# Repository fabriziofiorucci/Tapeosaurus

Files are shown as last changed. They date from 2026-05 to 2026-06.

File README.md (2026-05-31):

# Tapeosaurus

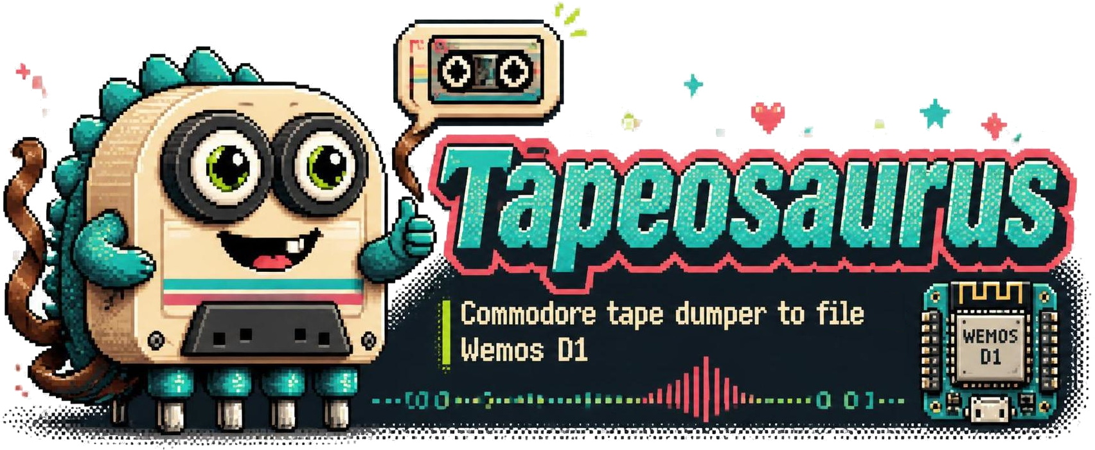
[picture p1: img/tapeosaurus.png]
Tapeosaurus


Cycle-accurate tape dumper for the **Commodore 16 / Plus/4**, **Commodore 64 / 128**, **ZX Spectrum**, and **MSX** running on a single Wemos D1 Mini (ESP8266) with a 3D-printable enclosure.

Inspired by Francesco Vannini's [TrueTape64](https://github.com/francescovannini/truetape64).

Supports C16/Plus4 standard tape and Novaload turbo, Commodore 64/128 tapes, ZX Spectrum standard ROM tapes, and MSX standard tapes — producing standard `.tap` v2 / `.tzx` / `.cas` files compatible with VICE, Fuse, Tapuino, TZXDuino, openMSX, and any other TAP/TZX/CAS-capable emulator or hardware.

---

## Supported tapes

* Commodore 16 & Plus4
* Commodore 64 & 128
* Spectrum
* MSX

---

## Hardware

### What you need

| Qty | Part | Note |
| --- | --- | --- |
| 1 | Wemos D1 Mini | Any revision; clones work fine |
| 1 | MP1584EN step-down module | Adjustable buck converter — set output to 5.00 V |
| 1 | MP1584EN step-down module | Adjustable buck converter — set output to 6.10 V |
| 1 | 10 kΩ resistor | READ voltage divider - in series with READ pin |
| 1 | 20 kΩ resistor | READ voltage divider - shunt to GND |
| 1 | 10 kΩ resistor | SENSE pull-up to 3.3 V |
| 1 | Green LED | "Tape play" indicator |
| 1 | Red LED | "Overflow" indicator |
| 1 | Yellow LED | "Power on" indicator |
| 2 | 390 Ω resistors | Green and red LED current limiters |
| 1 | 680 Ω resistor | Yellow LED current limiters |
| 1 | Passive piezo speaker | Tape audio feedback |
| 1 | 7-pin mini-DIN connector or salvaged cable | Commodore 16 Datasette connector |
| 1 | Mini tactile switch | Reset button |
| 1 | DC jack barrel connector with PCB mount | Power supply connector |
| 1 | >= 9V DC power supply | Powers both MP1584EN modules |

### MSX hardware notes

#### Using a Commodore tape player

MSX tapes can be dumped using a Commodore datasette, no firmware changes required.

#### Connecting an MSX tape player

MSX computers read tape via the **EAR** pin on the cassette connector (a 3.5 mm DIN jack or 8-pin DIN depending on the model). The EAR pin carries the audio signal from the tape deck at roughly 1 Vpp.

Use the same 10 kΩ / 20 kΩ voltage divider on the READ line as for Commodore tapes. No firmware changes are required — the `tapeosaurus.ino` sketch is identical; the CLI selects CHANGE edge mode automatically when `-model msx` is used.

#### MSX tape format

MSX uses a **Kansas City Standard (KCS)** variant FSK encoding:

| Baud rate | Bit 0 | Bit 1 |
|---|---|---|
| 1200 baud | 1 cycle @ 1200 Hz | 2 cycles @ 2400 Hz |
| 2400 baud | 1 cycle @ 2400 Hz | 2 cycles @ 4800 Hz |

Each byte is framed as: 1 start bit (0), 8 data bits (LSB first), 2 stop bits (1).

Output is a standard **.cas** file containing the 8-byte CAS sync header (`1F A6 DE BA CC 13 7D 74`) followed by decoded data, compatible with openMSX, fMSX, BlueMSX, CASDuino, and TZXDuino/CASduino.

### ZX Spectrum hardware notes

#### Using a Commodore tape player

Spectrum tapes can be dumped using a Commodore datasette, no firmware changes required.

#### Using a standard tape player

The Spectrum EAR socket outputs a 5 V audio signal (not TTL).  The same
**10 kΩ / 20 kΩ voltage divider** used for the Commodore READ line is suitable
here — connect the EAR tip to the divider input and the sleeve to GND.

The Spectrum has no motor-control line equivalent to SENSE; the capture starts
as soon as the CLI detects the first pulse.  Because `CAPTURE_WITHOUT_SENSE`
defaults to `0`, the firmware waits for the SENSE pin to go LOW before it
starts storing pulses.  For Spectrum use, either:

- wire a simple switch to the SENSE pin (pull it LOW when you press PLAY), **or**
- recompile the firmware with `#define CAPTURE_WITHOUT_SENSE 1` (the CLI will
  still wait for the first `CMD_PLAY_PRESSED` event, which in this mode fires
  on the first pulse rather than on the SENSE signal).

### Pin mapping

| Wemos Pin | GPIO | Function |
| --- | --- | --- |
| D1 | GPIO5  | Overflow LED (lit if data overflow triggered) |
| D4 | GPIO2  | Onboard LED (active LOW - lit while recording) |
| D5 | GPIO14 | SENSE from Datasette (INPUT\_PULLUP, switch to GND) |
| D6 | GPIO12 | READ from Datasette (via 10 kΩ/20 kΩ divider → 3.3 V) |
| D7 | GPIO13 | Passive piezo speaker |

### Schematics

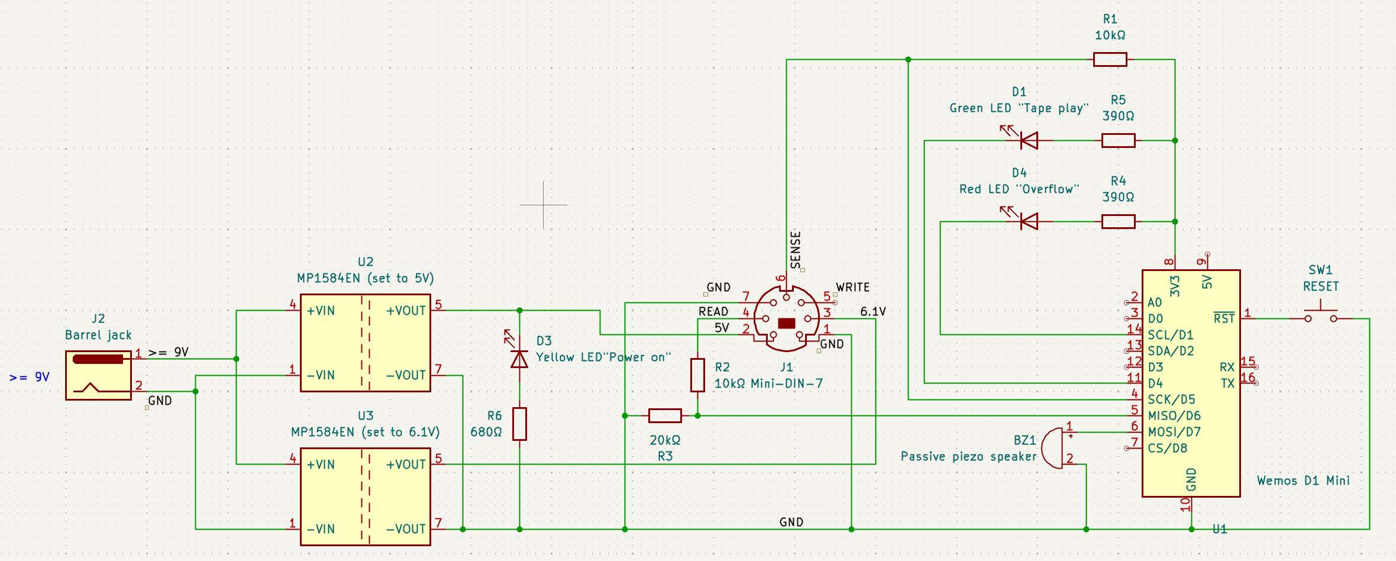
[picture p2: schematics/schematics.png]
Schematics


> ⚠ The ESP8266 is a 3.3 V device. The Datasette/EAR READ line is 5 V. The 10 kΩ / 20 kΩ divider is **mandatory** — skipping it will damage GPIO12.

### 3D-printable enclosure

Autodesk Fusion 360 files are provided [here](CAD).

### MP1584EN Step-Down Calibration

Each module must be pre-adjusted before connecting the Datasette.

**Module U2 — 5 V (Datasette logic supply)** Connect 12 V, measure OUT+ and adjust the trimpot to 5.00 V.

**Module U3 — 6.1 V (Datasette motor)** Connect 12 V, measure OUT+ and adjust the trimpot to 6.10–6.15 V. Recheck with the motor spinning under load. Values above 6.5 V risk burning the motor winding.

### Quick Sanity Checks Before First Use

- [ ] MP1584EN-U2 output reads 5.00 V (Datasette logic supply)
- [ ] MP1584EN-U3 output reads 6.10–6.15 V on MOTOR line (Datasette disconnected)
- [ ] Multimeter reads ~3.3 V on Wemos 3V3 pin
- [ ] SENSE pin reads ~3.3 V at idle (no tape playing)
- [ ] SENSE pin reads ~0 V when PLAY is pressed (with cassette inserted)
- [ ] No short between 5V and GND (continuity check — no beep)
- [ ] READ pin reads ~3.3 V with tape playing (signal swings around this level)

---

## Firmware

### Requirements

- Arduino IDE 1.8+ or 2.x
- ESP8266 Arduino core — add this URL in **File → Preferences → Additional Boards Manager URLs**:
`https://arduino.esp8266.com/stable/package_esp8266com_index.json`

### Board settings

| Setting | Value |
| --- | --- |
| Board | LOLIN(WEMOS) D1 R2 & mini |
| CPU Frequency | **80 MHz** ← must be 80, not 160 |
| Upload Speed  | 921600 |

> The `CLOCK_SCALE 40` constant (80 MHz ÷ 40 = 2 MHz ticks) is hardcoded. Changing CPU frequency without updating this value will corrupt all timing.

### Tuning options

| Define | Default | Description |
| --- | --- | --- |
| `CAPTURE_WITHOUT_SENSE` | `0` | Set to `1` to capture without waiting for PLAY — useful for Spectrum or READ wiring tests |

> Edge mode (FALLING/CHANGE) is not a compile-time setting. It is controlled entirely at runtime by the Python CLI over the serial control protocol. The default on power-up is FALLING (standard KERNAL) — safe until the CLI sets it otherwise.  For `-model spectrum` the CLI automatically sends `HOST_CMD_CHANGE` before capture.

---

## Python CLI

### Install

```
pip install -r cli/requirements.txt
```

### Usage

```
# Standard C16/Plus4 tape (PAL)
python3 cli/tapeosaurus.py -p /dev/ttyUSB0 -model c16 output.tap

# C16/Plus4 Novaload turbo
python3 cli/tapeosaurus.py -p /dev/ttyUSB0 -model c16 --novaload output.tap

# C16/Plus4 NTSC machine
python3 cli/tapeosaurus.py -p /dev/ttyUSB0 -model c16 --ntsc output.tap

# C16/Plus4 Extract PRG files after capture
python3 cli/tapeosaurus.py -p /dev/ttyUSB0 -model c16 --prg output.tap

# C64/128 tape (PAL)
python3 cli/tapeosaurus.py -p /dev/ttyUSB0 -model c64 output.tap

# ZX Spectrum tape → TZX (default, recommended)
python3 cli/tapeosaurus.py -p /dev/ttyUSB0 -model spectrum output.tzx

# ZX Spectrum tape → raw .tap
python3 cli/tapeosaurus.py -p /dev/ttyUSB0 -model spectrum --tap output.tap

# ZX Spectrum tape → TZX + extract .bin files
python3 cli/tapeosaurus.py -p /dev/ttyUSB0 -model spectrum --prg output.tzx

# MSX tape (1200 baud, default)
python3 cli/tapeosaurus.py -p /dev/ttyUSB0 -model msx output.cas

# MSX tape (2400 baud high-speed)
python3 cli/tapeosaurus.py -p /dev/ttyUSB0 -model msx --baud 2400 output.cas

# MSX tape → CAS + extract files
python3 cli/tapeosaurus.py -p /dev/ttyUSB0 -model msx --prg output.cas
```

Passing `--novaload` is required for C16/Plus4 Novaload turbo tapes. The CLI automatically sends the correct edge mode command to the ESP before waiting for PLAY, then selects the appropriate decode path after capture. No switches, no recompile.

### What happens at startup

1. CLI connects and waits 2 seconds for the ESP to boot
2. Sends `CMD_SET_EDGE_FALLING` or `CMD_SET_EDGE_CHANGE` depending on model / flags
3. Waits up to 3 seconds for the ESP's confirmation echo
4. Prints the confirmed edge mode and waits for PLAY

```
C16/Plus4 PAL — scale: 0.443362
Capturing → output.tap
→  Setting edge mode: FALLING (standard)
✔  Edge mode confirmed by device: FALLING (standard)
Waiting for PLAY (LED lights up)...
```

```
C64 PAL — scale: 0.492624
Capturing → output.tap
→  Setting edge mode: FALLING (standard)
✔  Edge mode confirmed by device: FALLING (standard)
Waiting for PLAY (LED lights up)...
```

```
ZX Spectrum — 3.5 MHz — output: .tzx
Capturing → output.tzx
→  Setting edge mode: CHANGE (Novaload/turbo)
✔  Edge mode confirmed by device: CHANGE (Novaload/turbo)
Waiting for PLAY (LED lights up)...
```

```
MSX — 1200 baud — output: .cas
Capturing → output.cas
→  Setting edge mode: CHANGE (Novaload/turbo)
✔  Edge mode confirmed by device: CHANGE (Novaload/turbo)
Waiting for PLAY (LED lights up)...
```

### Real examples

#### Dumping a C16/Plus4 Novaload tape

```
$ python3 cli/tapeosaurus.py -p /dev/ttyUSB0 --novaload "./BMX Racers.tap"
C16/Plus4 Novaload PAL — scale: 0.443362
Capturing → ./BMX Racers.tap
→  Setting edge mode: CHANGE (Novaload/turbo)
✔  Edge mode confirmed by device: CHANGE (Novaload/turbo)
Waiting for PLAY (LED lights up)...
▶  RECORDING...
  … silence (2s)
✅ STOPPED — 313,211 pulses
✅ TAP written: ./BMX Racers.tap (313,244 B)
💡 Novaload turbo — use the raw TAP in YAPE/VICE or wav2prg
  Found: "8" ($0801–$0803, 3 B)
```

#### Dumping a C64/128 tape

```
$ python3 cli/tapeosaurus.py -p /dev/ttyUSB0 -model c64 "./Treasure Island.tap"
C64 PAL — scale: 0.492624
Capturing → ./Treasure Island.tap
→  Setting edge mode: FALLING (standard)
✔  Edge mode confirmed by device: FALLING (standard)
Waiting for PLAY (LED lights up)...
▶  RECORDING...
 … 460,000 pulses
✅ STOPPED — 461,633 pulses
✅ TAP written: ./Treasure Island.tap (461,860 B)
🔍 Decoding C64 KERNAL blocks...
  ⚠ No standard C64 KERNAL blocks found (sync not detected)
  Verify the tape is a standard (non-turbo) load, or try tapclean
💡 Full decode: wav2prg -P loaders --machine c64 --tap ./Treasure Island.tap
```

#### Dumping a ZX Spectrum tape

```
$ python3 cli/tapeosaurus.py -p /dev/ttyUSB0 -model spectrum --prg "Manic Miner.tzx"
ZX Spectrum — 3.5 MHz — output: .tzx
Capturing → Manic Miner.tzx
→  Setting edge mode: CHANGE (Novaload/turbo)
✔  Edge mode confirmed by device: CHANGE (Novaload/turbo)
Waiting for PLAY (LED lights up)...
▶  RECORDING...
  … 420,000 pulses
✅ STOPPED — 421,044 pulses
🔍 Decoding ZX Spectrum ROM blocks...

  Block 0: Header  ✔
    Type    : Bytes
    Name    : "Manic Min"
    Length  : 49152 bytes
    Load    : $8000
  Block 1: Data    ✔  (49152 bytes payload)

✅ TZX written: Manic Miner.tzx (98,340 B)
  ✅ BIN: Manic_Min.bin (49152 B, load $8000)
💡 Spectrum TZX compatible with: Fuse, SpecEmu, ZXSpin, TZXDuino
💡 Full decode: tzxtools --info Manic Miner.tzx
```

#### Dumping an MSX tape

```
$ python3 cli/tapeosaurus.py -p /dev/ttyUSB0 -model msx --prg "Knightmare.cas"
MSX — 1200 baud — output: .cas
Capturing → Knightmare.cas
→  Setting edge mode: CHANGE (Novaload/turbo)
✔  Edge mode confirmed by device: CHANGE (Novaload/turbo)
Waiting for PLAY (LED lights up)...
▶  RECORDING...
  … 580,000 pulses
✅ STOPPED — 581,290 pulses
🔍 Decoding MSX tape blocks...

  Block 0: Binary    "KNIGHT"  (16406 bytes)  load=$E000 end=$FFFF entry=$E000

✅ CAS written: Knightmare.cas (16,422 B)
  ✅ BIN: KNIGHT.bin (16384 B @ $E000)
💡 CAS compatible with: openMSX, fMSX, BlueMSX, CASDuino, TZXDuino
💡 Full decode: cas2wav Knightmare.cas output.wav
```

### Machine clock reference

| Machine | Clock | Notes |
| --- | --- | --- |
| Commodore 16 / Plus4 (standard) | 886 724 Hz PAL / 894 886 Hz NTSC | |
| Commodore 16 / Plus4 (Novaload) | 886 724 Hz PAL / 894 886 Hz NTSC | |
| Commodore 64 / 128 | 985 248 Hz PAL / 1 022 727 Hz NTSC | |
| ZX Spectrum (all models) | 3 500 000 Hz | Fixed; --ntsc has no effect |
| MSX (all models) | FSK / KCS — 1200 or 2400 baud | Decoded from pulse widths; --ntsc has no effect |

The firmware always outputs 2 MHz-equivalent ticks; the CLI scales them to the correct machine clock before writing the TAP/TZX file.

---

## ZX Spectrum — Technical Details

### Timing constants (3.5 MHz T-states)

| Signal | T-states |
| --- | --- |
| Pilot half-pulse  | 2168 |
| Sync-1 half-pulse | 667 |
| Sync-2 half-pulse | 735 |
| Bit-0 half-pulse  | 855 × 2 |
| Bit-1 half-pulse  | 1710 × 2 |

### Block types

| Flag byte | Meaning |
| --- | --- |
| 0x00 | Header block (19 bytes payload) |
| 0xFF | Data block (variable payload) |

### Header block layout (flag = 0x00, 17 payload bytes)

| Offset | Size | Field | Notes |
| --- | ---- | --- | --- |
| 0 | 1 | type | 0=Program 1=NumArray 2=CharArray 3=Code/Bytes |
| 1 | 10 | filename | space-padded ASCII |
| 11 | 2 | length | data block payload length |
| 13 | 2 | param1 | Program: LINE; Code: load address |
| 15 | 2 | param2 | Program: BASIC length; Code: 0x8000 |

### Output formats

**TZX (default, `-model spectrum`)** — Standard Speed Data blocks (0x10) for
each decoded ROM block.  If no ROM blocks are decoded (e.g. custom/turbo
loader), a Direct Recording block (0x15) is written at 2 MHz sample rate so
the raw waveform is preserved.  Compatible with Fuse, SpecEmu, ZXSpin,
RealSpectrum, TZXDuino, and PZX2TZX tools.

**TAP (`--tap`)** — Raw `.tap` block stream, compatible with Fuse `--tape`,
ZX-Uno, and RetroVirtualMachine.  Only available when ROM blocks are
successfully decoded; custom loaders should use TZX.

---

## MSX — Technical Details

### Tape encoding (Kansas City Standard variant)

MSX uses **Frequency Shift Keying (FSK)** based on the Kansas City Standard:

| Baud rate | Bit 0 | Bit 1 | Header tone |
| --- | ----- | ----- | --- |
| 1200 baud | 1 cycle @ 1200 Hz (833 µs) | 2 cycles @ 2400 Hz (417 µs) | 2400 Hz × 16 000 half-pulses (~6.7 s) |
| 2400 baud | 1 cycle @ 2400 Hz (417 µs) | 2 cycles @ 4800 Hz (208 µs) | 4800 Hz × 32 000 half-pulses (~6.7 s) |

A **short header** (~1.7 s) separates the file header record from the data body.

Each byte is framed as: **1 start bit (0) + 8 data bits LSB-first + 2 stop bits (1)** — 11 bits total.

The signal is captured in **CHANGE edge mode** (both edges), identical to the Spectrum path.

### CAS sync word and file type markers

Every logical block on tape begins with the 8-byte sync word, followed by 10 repeating type-marker bytes:

| Sync word (hex) | `1F A6 DE BA CC 13 7D 74` |
| --- | --- |
| BASIC tokenised marker | `D3 D3 D3 D3 D3 D3 D3 D3 D3 D3` |
| ASCII / text marker | `EA EA EA EA EA EA EA EA EA EA` |
| Binary / machine code marker  | `D0 D0 D0 D0 D0 D0 D0 D0 D0 D0` |

### File header record layout

The 6-byte filename (space-padded) follows immediately after the 10 type-marker bytes.  For binary (BSAVE) files, three 2-byte little-endian words follow the filename:

| Offset | Size | Field | Notes |
| --- | ---- | --- | --- |
| 10 | 6 | filename | space-padded ASCII |
| 16 | 2 | start address | load address |
| 18 | 2 | end address | inclusive |
| 20 | 2 | entry address | execution entry point  |

### Output format

**CAS (`.cas`)** — Standard MSX cassette image.  Each block is stored as the 8-byte CAS sync word followed by the raw decoded data (type markers + filename + payload).  Compatible with openMSX (`-cassetteplayer`), fMSX, BlueMSX, CASDuino, TZXDuino/CASduino, and `cas2wav`.

Pass `--prg` to additionally extract individual files:
- Binary (BSAVE) blocks → `.bin` (raw payload, load address shown in output)
- BASIC tokenised blocks → `.bas` (raw tokenised BASIC, load with openMSX BASIC `BLOAD`)
- ASCII / text blocks → `.asc`

---

## How it works

### Timing

1. A GPIO ISR fires on every pulse boundary (`FALLING` for standard, `CHANGE` for Novaload/Spectrum).
2. `ESP.getCycleCount()` is sampled inside the ISR — an 80 MHz hardware counter.
3. The delta between consecutive calls is divided by 40 to produce a 2 MHz tick unit.
4. Ticks are clamped to 24 bits and pushed into a 4096-entry ring buffer.
5. `loop()` drains the buffer to serial at 250 000 baud.

Wi-Fi is completely disabled at boot to eliminate scheduler jitter.

### Control protocol

All serial frames are exactly 4 bytes, in both directions.
The `[FF][FF][FF][CMD]` structure is used for host→device commands and `[00][00][00][CMD]` device→host events.

Device is Wemos D1 ESP, Host is the Linux host where `tapeosaurus.py` is run.

**Device → Host:**

| Frame | Bytes | Meaning |
| --- | --- | --- |
| Pulse data | `[B0][B1][B2][B0^B1^B2]` | 24-bit tick count, 2 MHz clock, LSB first |
| PLAY pressed | `[00][00][00][01]` | Tape started — begin recording |
| PLAY released | `[00][00][00][02]` | Tape stopped — end recording |
| Overflow | `[00][00][00][03]` | Ring buffer full, data lost |
| Edge mode change | `[00][00][00][04]` | Confirmation: edge-mode changed |

**Host → Device:**

| Frame | Bytes | Meaning |
| --- | --- | --- |
| Set FALLING | `[FF][FF][FF][10]` | Switch to FALLING edge (standard KERNAL) |
| Set CHANGE  | `[FF][FF][FF][11]` | Switch to CHANGE edge (Novaload / Spectrum / turbo) |

---

## Troubleshooting

| Symptom | Likely cause | Fix |
| --- | --- | --- |
| `⚠ No echo from device` at startup | ESP not ready or baud mismatch | Check baud is 250 000 in both CLI and Arduino IDE; power-cycle the Wemos |
| 0 pulses captured | READ wiring or wrong edge mode | Set `CAPTURE_WITHOUT_SENSE 1` to test READ independently; verify `--novaload` flag matches tape type |
| Novaload tape loads garbled | Edge mode mismatch | Ensure `--novaload` is passed for turbo tapes |
| Frame error: timeout before tape starts | Normal — motor spin-up gap | CLI tolerates 30 s of silence before stopping |
| Motor doesn't spin / spins wrong speed  | MP1584EN-U3 not calibrated | Set to 6.10–6.15 V with a multimeter before connecting |
| Overflow LED lights up | Buffer draining too slowly | Check baud is 250 000; close other apps using the port |
| Garbled timing | CPU not at 80 MHz | Check board settings in Arduino IDE |
| Datasette not powering on | MP1584EN-U2 not calibrated | Verify 5 V output before connecting Datasette |
| Spectrum: no blocks decoded | Custom/turbo loader | TZX Direct Recording block is still written — use tzxtools or PlayTZX to play it back |
| Spectrum: bad checksum warnings | Worn tape or level mismatch | Try adjusting the EAR volume on the source device; increase divider tolerance |
| Spectrum: SENSE never fires | No SENSE wiring | Compile with `CAPTURE_WITHOUT_SENSE 1` for Spectrum use |
| MSX: no blocks decoded | Wrong baud rate | Try `--baud 2400`; most commercial game tapes are 1200 baud but some publishers used 2400 |
| MSX: garbled data | Signal level too high/low (not applicable when Commodore datasette is used) | Adjust tape deck volume; verify 10 kΩ/20 kΩ divider is fitted on the EAR line |
| MSX: SENSE never fires | No SENSE wiring (not applicable when Commodore datasette is used) | Compile with `CAPTURE_WITHOUT_SENSE 1`; MSX has no motor-control equivalent to Datasette SENSE |

---

## Tested tapes

Here's a list of successfully [tested tapes](TAPES.md).

---

## Credits & license

Inspired by [TrueTape64](https://github.com/francescovannini/truetape64) by Francesco Vannini.

**License:** GNU General Public License v3.0

---

*Made for the Commodore, Spectrum and MSX preservation community · Long live the Datasette 🖤*

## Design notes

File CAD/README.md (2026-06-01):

## Tapeosaurus: Enclosure

This repository folder contains the 3D design and print files for the Tapeosaurus enclosure. Use these files to modify, inspect, or 3D-print the enclosure that fits the Tapeosaurus electronics.

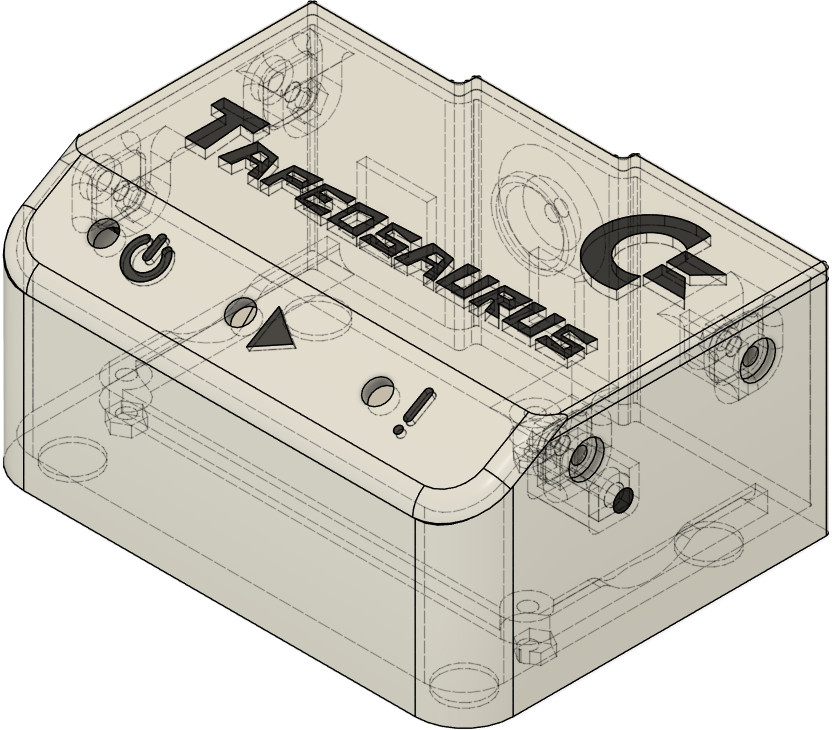
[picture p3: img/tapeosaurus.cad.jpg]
Tapeosaurus enclosure


<p align="middle">
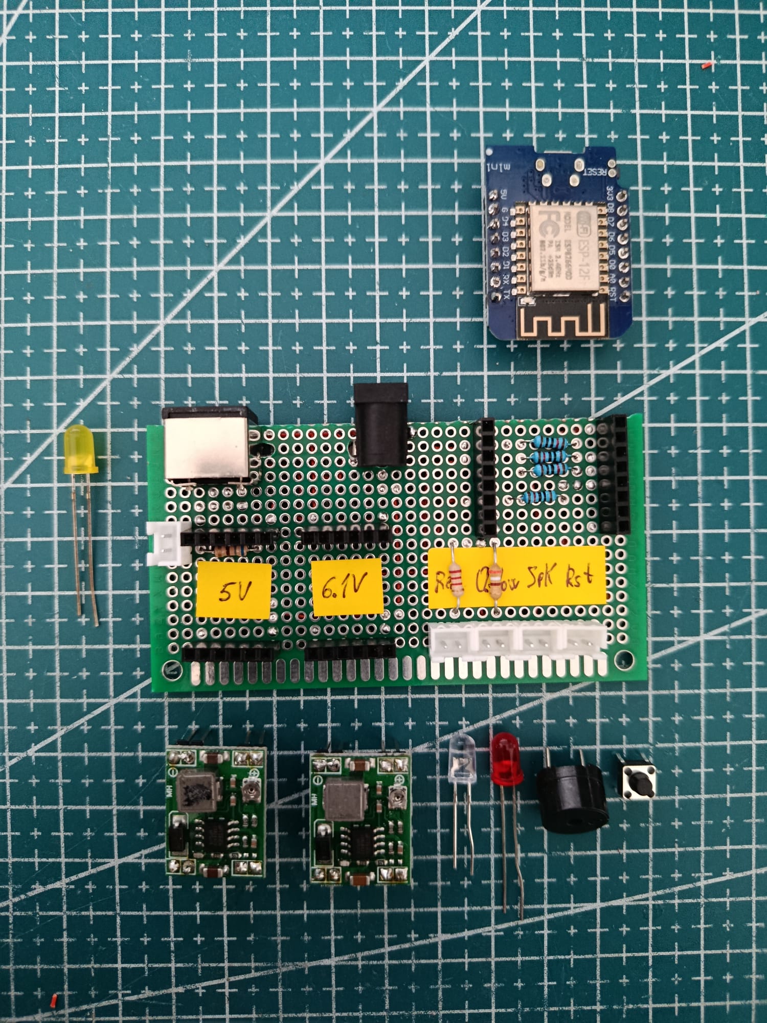
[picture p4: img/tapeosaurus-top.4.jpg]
Tapeosaurus components
  
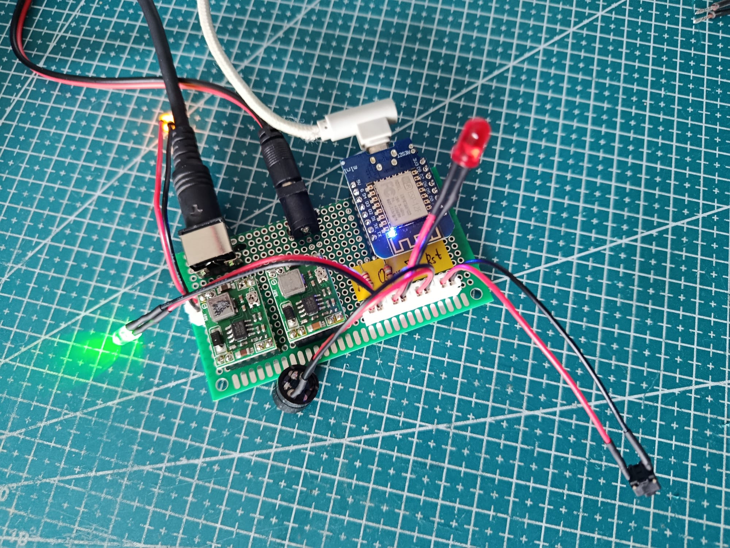
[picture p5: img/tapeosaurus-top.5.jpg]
Tapeosaurus board
  
</p>
<p align="middle">
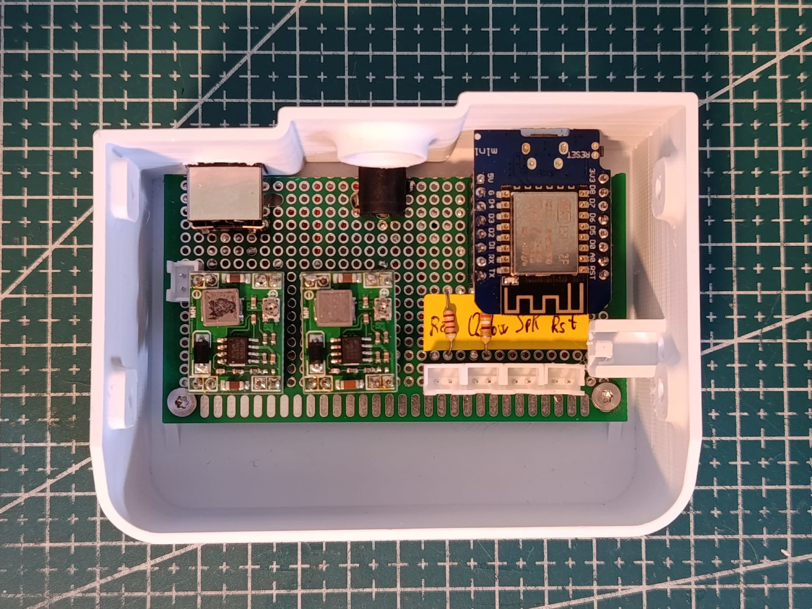
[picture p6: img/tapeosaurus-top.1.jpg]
Tapeosaurus enclosure top view 1
  
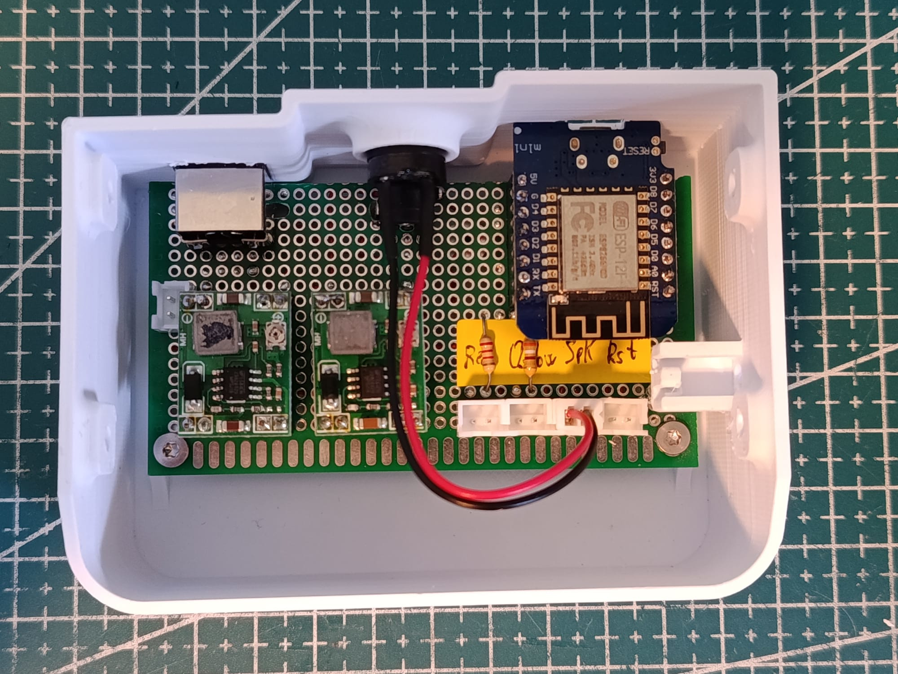
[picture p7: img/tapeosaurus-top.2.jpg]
Tapeosaurus enclosure top view 2
  
</p>
<p align="middle">
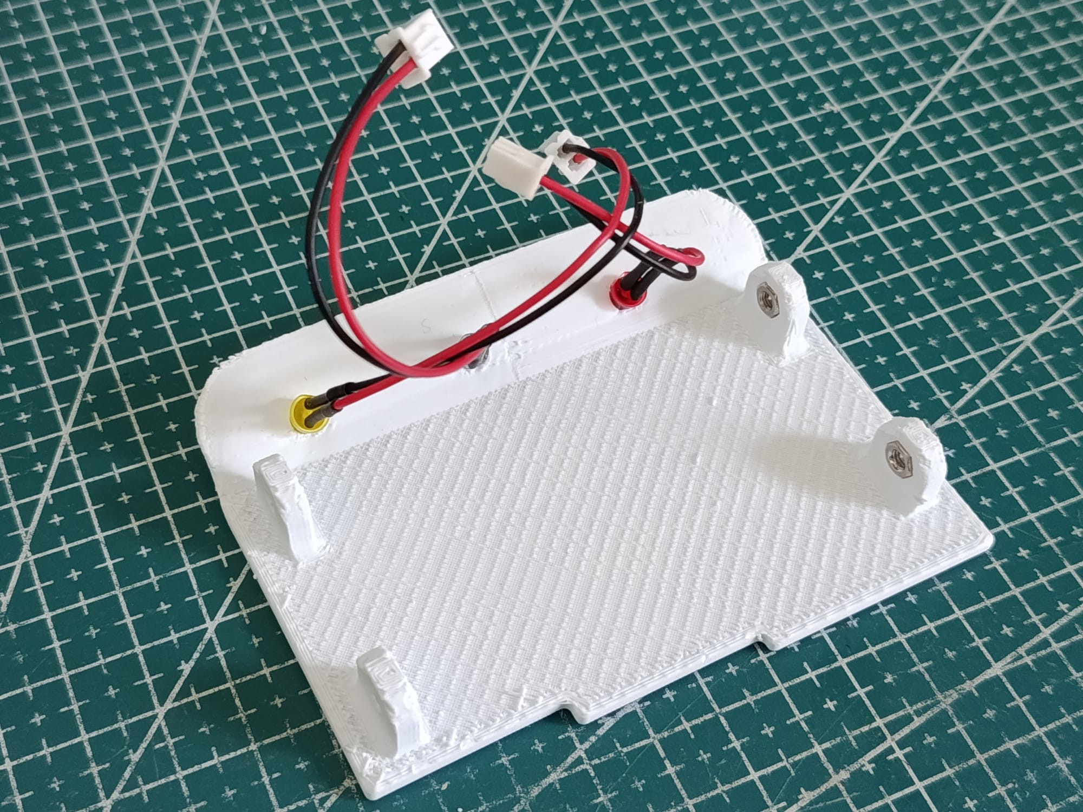
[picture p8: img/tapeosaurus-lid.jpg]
Tapeosaurus enclosure lid
  
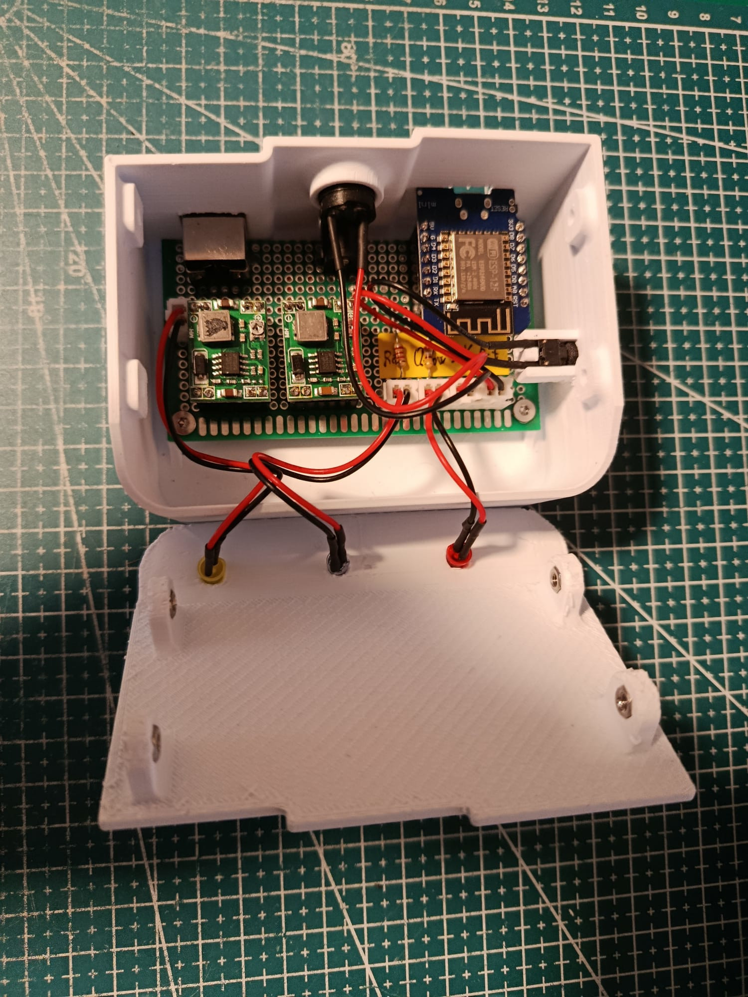
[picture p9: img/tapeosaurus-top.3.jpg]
Tapeosaurus enclosure top view 3
  
</p>
<p align="middle">
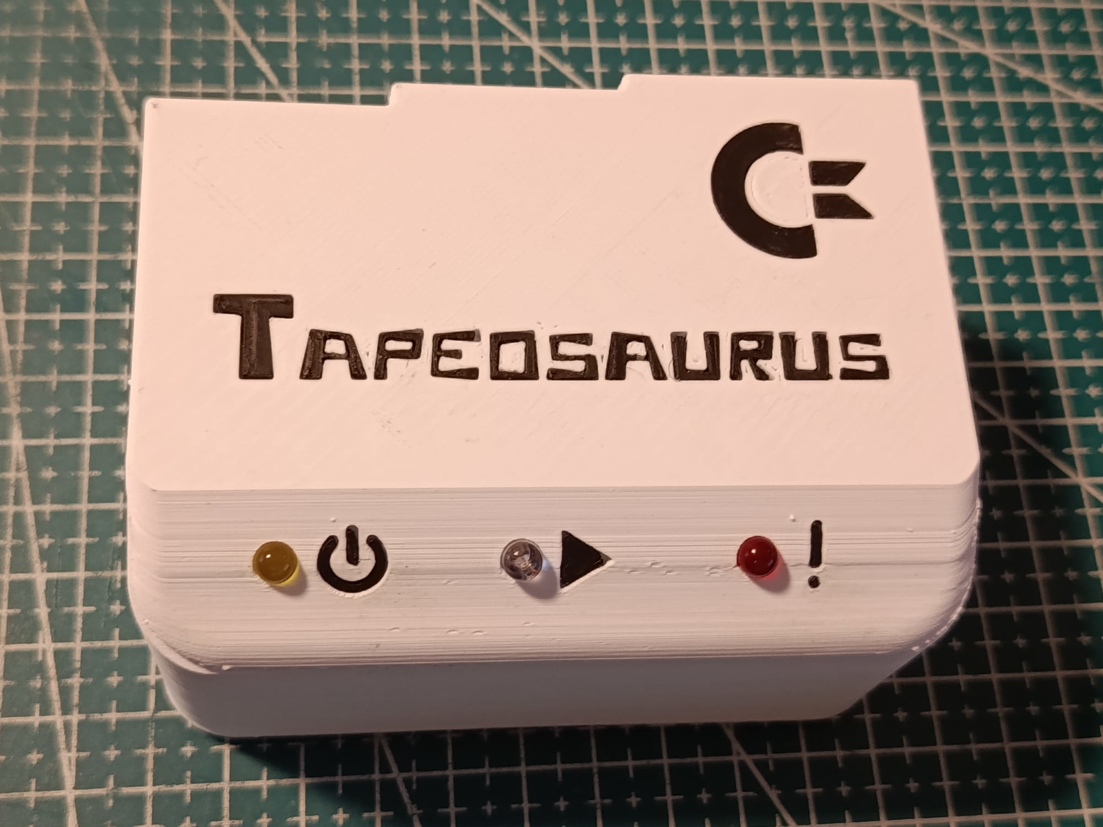
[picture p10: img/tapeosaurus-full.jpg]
Tapeosaurus enclosure full
  
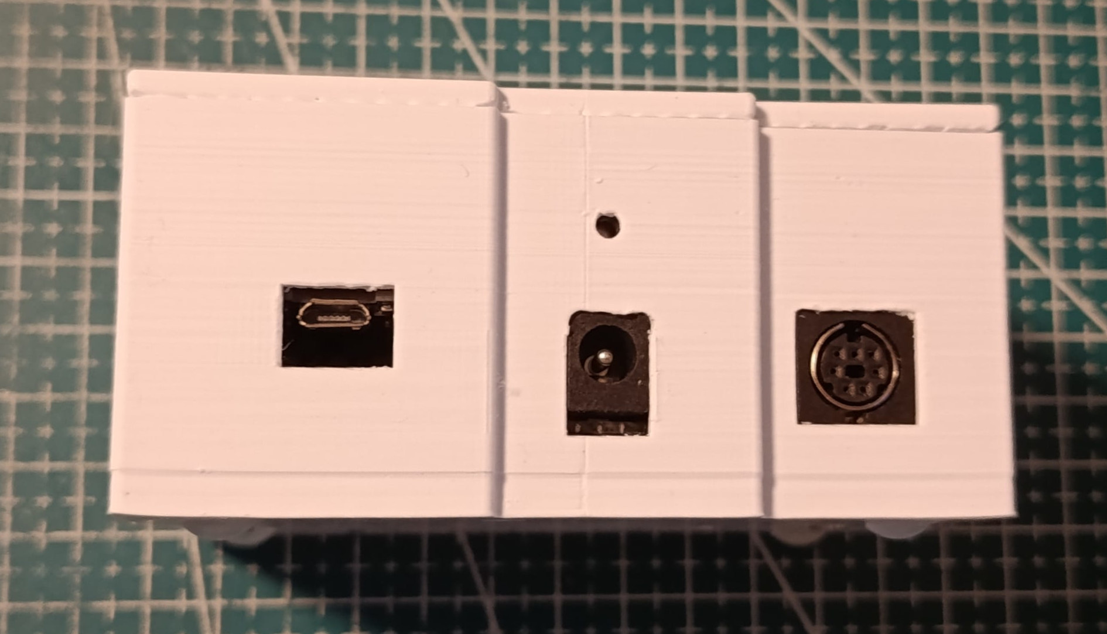
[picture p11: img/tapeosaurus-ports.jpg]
Tapeosaurus enclosure ports side
  
</p>

### Contents
- Fusion 360 source [Tapeosaurus.f3d](Tapeosaurus.f3d) — complete Fusion 360 archive with all bodies, sketches, and appearance setup.
- 3D printable parts in the [stl](stl) directory

### Recommended print settings
- Material: PLA (black and white)
- Layer height: 0.10 mm
- Perimeters: 3
- Infill: 15–20%
- Supports: main body and lid

### Customization tips
- To change the logo or button legends, open Tapeosaurus-enclosure.f3d and edit the emboss/cut features in the top body.
- To accommodate a different PCB or connector, modify standoff locations and cutouts in the Fusion 360 file, then re-export STLs.
- For better snap-fit, add chamfers or flexible hooks in Fusion and test with a single calibration print.

### License & attribution
- These CAD and print files are distributed under the license at the repository root (see LICENSE). If no license is present, ask the project owner before redistributing or reusing commercially.
- If you publish modified enclosures derived from these files, please credit the Tapeosaurus project.

### Contact / contributions
- To propose improvements, open a GitHub issue or submit a pull request with updated F3D and exported STLs.
- Include test prints and notes about printer/model/settings when submitting changes.

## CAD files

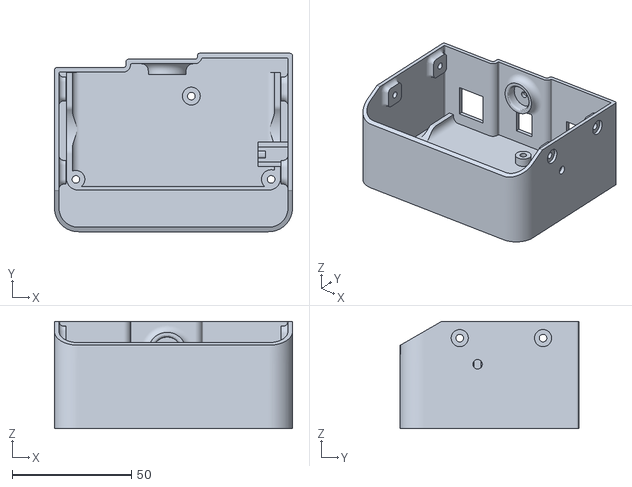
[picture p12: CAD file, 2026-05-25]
CAD/stl/Tapeosaurus - Main body.stl
100.0 x 75.0 x 45.0

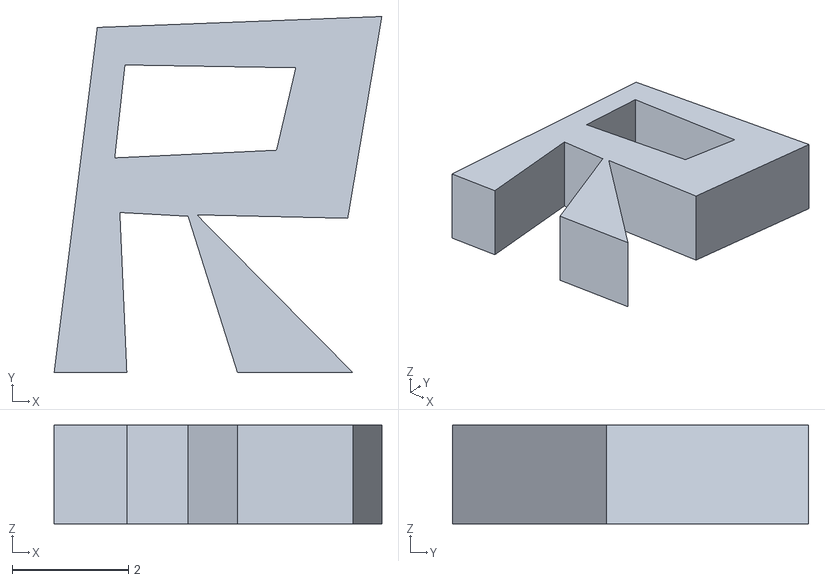
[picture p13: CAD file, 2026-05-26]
CAD/stl/R.stl
5.63 x 6.12 x 1.70

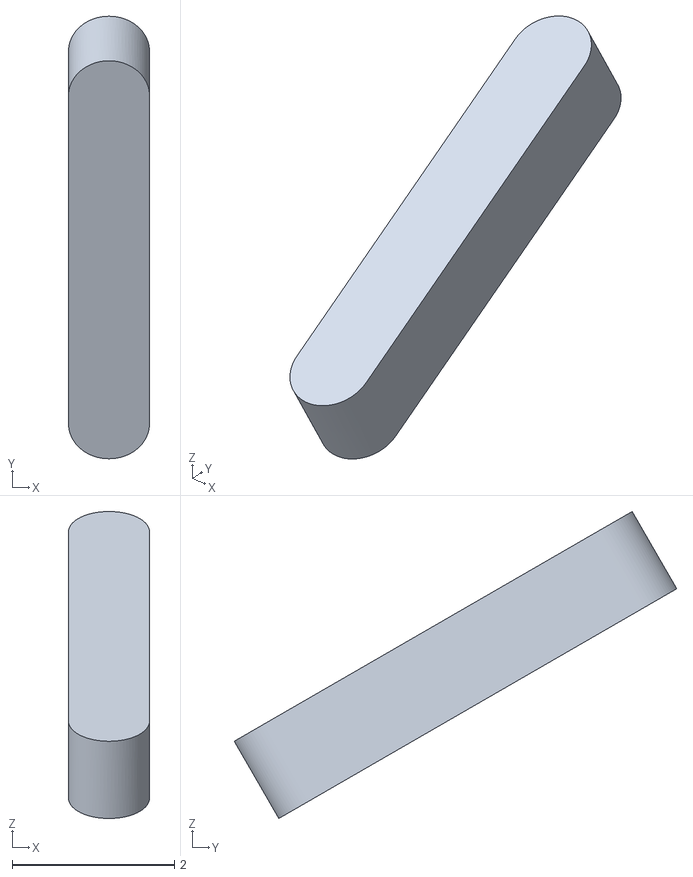
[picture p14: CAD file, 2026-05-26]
CAD/stl/Overflow 1.stl
1.00 x 5.46 x 3.79

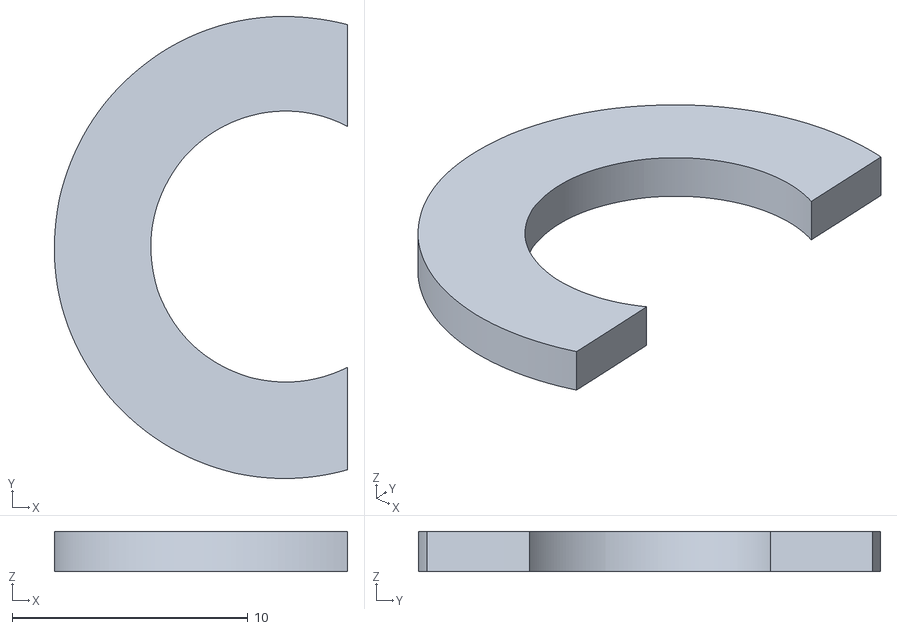
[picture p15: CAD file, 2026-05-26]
CAD/stl/CBM Logo 3.stl
12.4 x 19.6 x 1.70

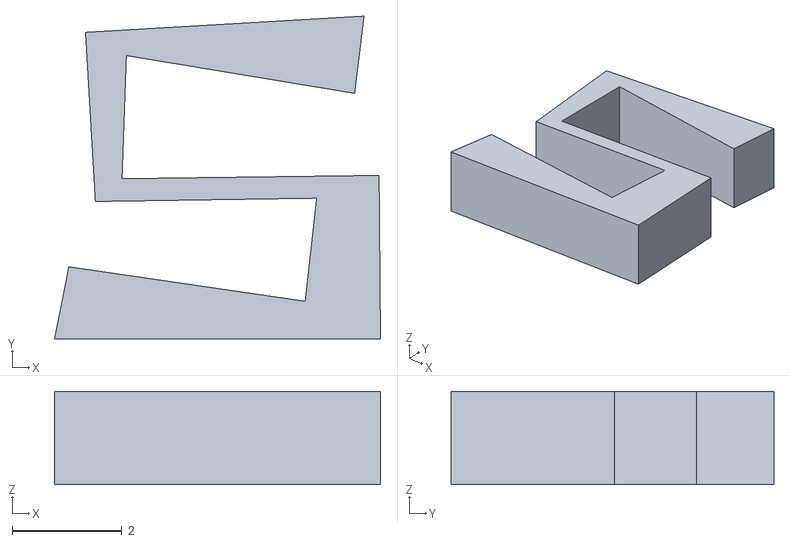
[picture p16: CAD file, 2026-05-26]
CAD/stl/S.stl
5.93 x 5.87 x 1.70

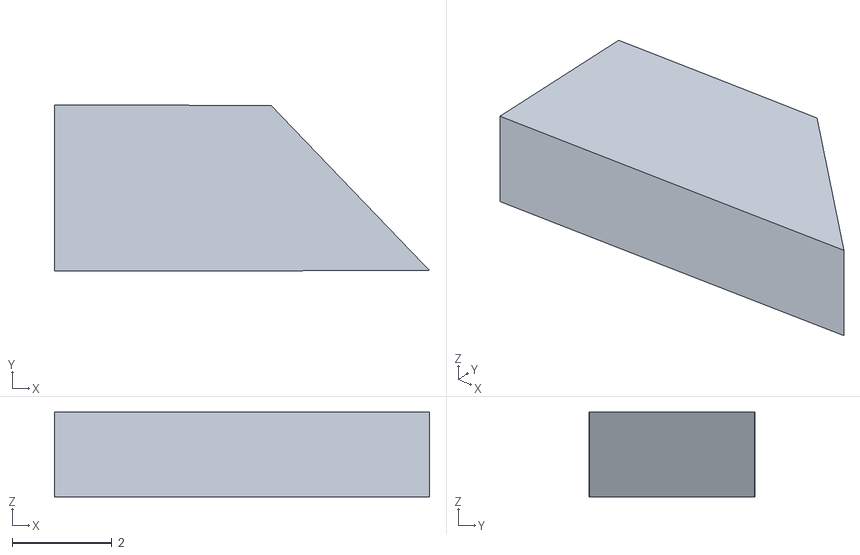
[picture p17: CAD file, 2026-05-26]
CAD/stl/CBM Logo 2.stl
7.53 x 3.33 x 1.70

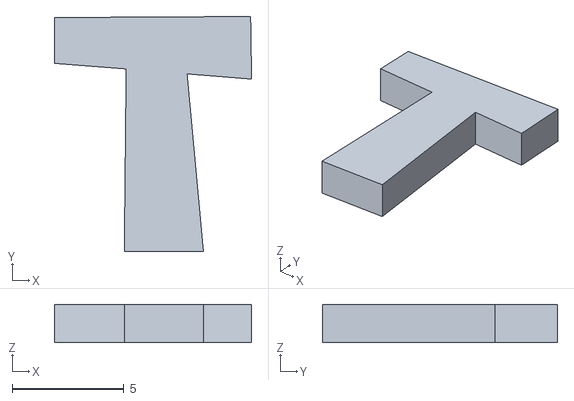
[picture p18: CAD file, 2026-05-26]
CAD/stl/T.stl
8.81 x 10.5 x 1.70

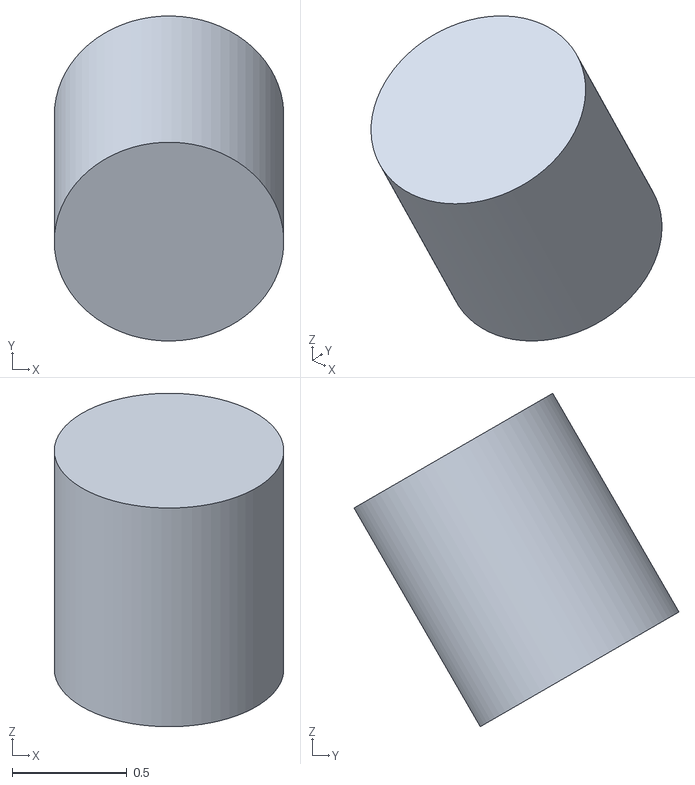
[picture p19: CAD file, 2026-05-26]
CAD/stl/Overflow 2.stl
1 x 1.42 x 1.45

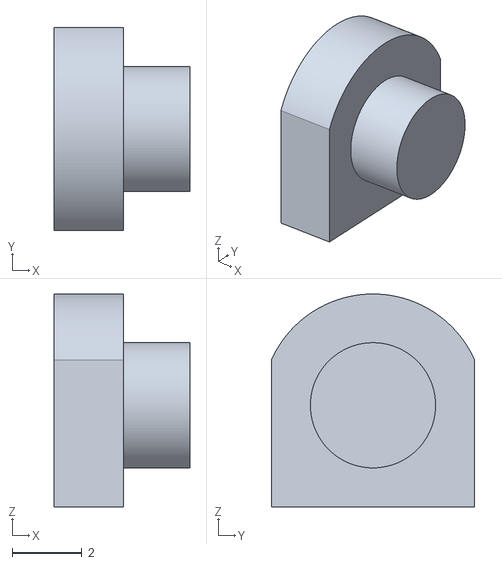
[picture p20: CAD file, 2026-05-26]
CAD/stl/Reset button.stl
3.90 x 5.85 x 6.12

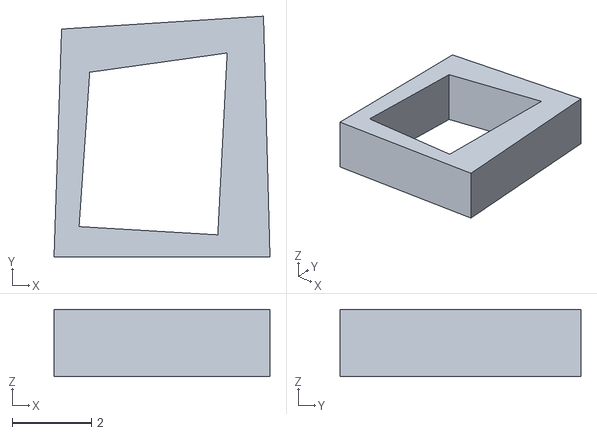
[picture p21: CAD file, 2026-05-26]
CAD/stl/O.stl
5.46 x 6.08 x 1.70

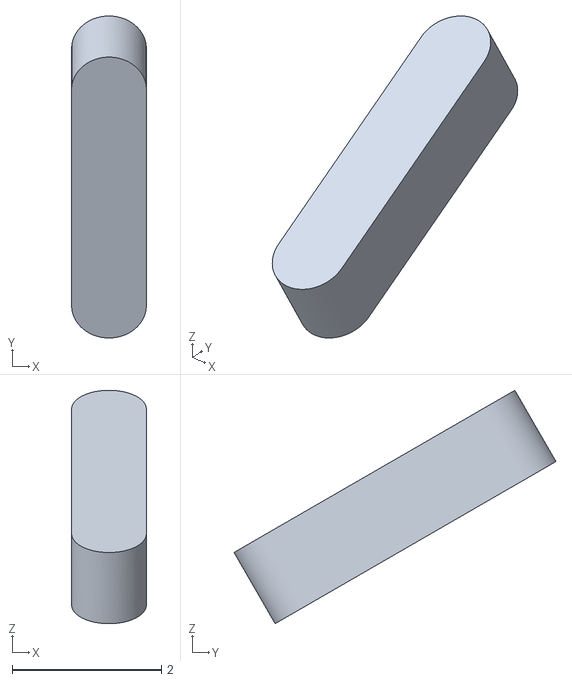
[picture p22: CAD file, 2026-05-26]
CAD/stl/On 2.stl
1.00 x 4.31 x 3.12

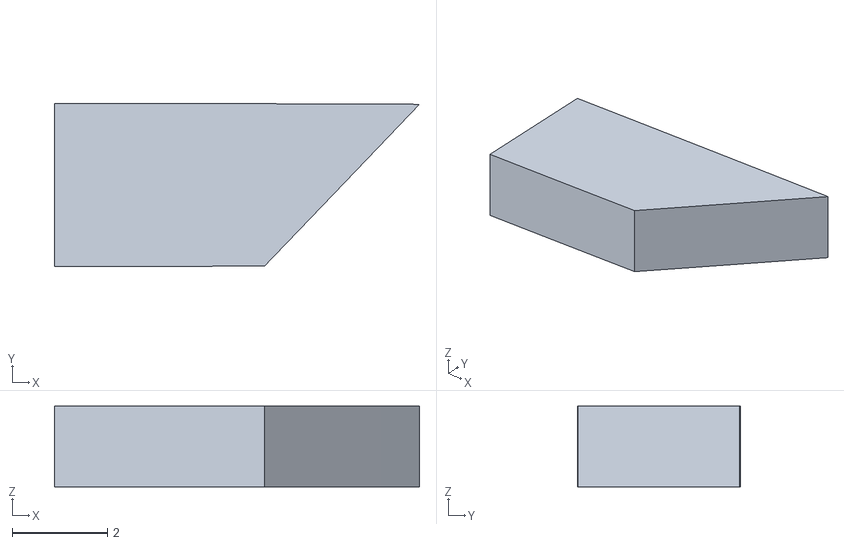
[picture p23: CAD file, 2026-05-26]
CAD/stl/CBM Logo 1.stl
7.68 x 3.43 x 1.70

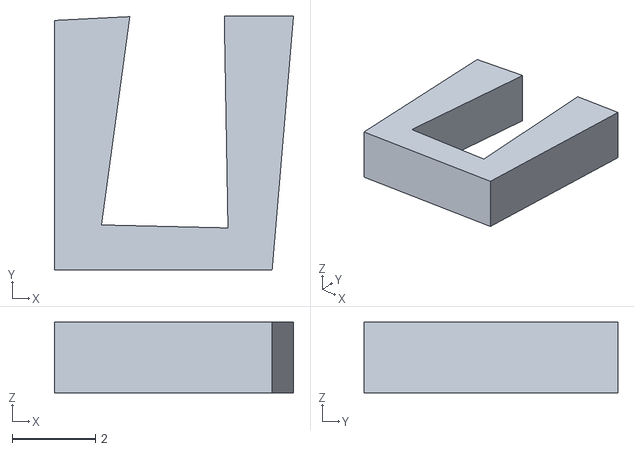
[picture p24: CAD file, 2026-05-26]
CAD/stl/U.stl
5.74 x 6.10 x 1.70

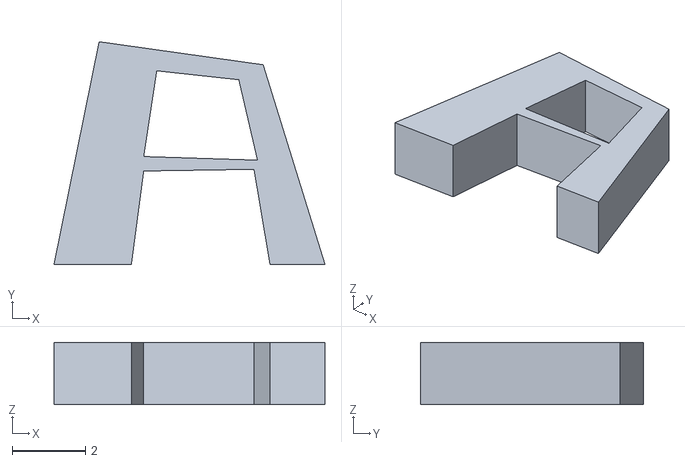
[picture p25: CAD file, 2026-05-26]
CAD/stl/A.stl
7.39 x 6.07 x 1.70

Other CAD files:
CAD/stl/P.stl
CAD/stl/E.stl
CAD/stl/On 1.stl
CAD/stl/Play.stl
CAD/Tapeosaurus.f3d
CAD/stl/A (1).stl
CAD/stl/S (1).stl
CAD/stl/Tapeosaurus - Lid.stl
CAD/stl/U (1).stl

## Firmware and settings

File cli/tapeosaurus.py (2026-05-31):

#!/usr/bin/env python3

"""
Tapeosaurus — C16/Plus4, C64, ZX Spectrum and MSX TAP/TZX/CAS capture + extraction

Usage:
  python3 tapeosaurus.py -p /dev/ttyUSB0 out.tap
  python3 tapeosaurus.py -p /dev/ttyUSB0 -model c64 out.tap
  python3 tapeosaurus.py -p /dev/ttyUSB0 --prg out.tap
  python3 tapeosaurus.py -p /dev/ttyUSB0 -model c16 --novaload out.tap   (C16 only)
  python3 tapeosaurus.py -p /dev/ttyUSB0 -model spectrum out.tzx
  python3 tapeosaurus.py -p /dev/ttyUSB0 -model spectrum --tap out.tap
  python3 tapeosaurus.py -p /dev/ttyUSB0 -model msx out.cas
  python3 tapeosaurus.py -p /dev/ttyUSB0 -model msx --baud 2400 out.cas

Edge mode is negotiated automatically:
  --novaload → sends HOST_CMD_CHANGE (CHANGE interrupt, both edges) — C16 only
  (default)  → sends HOST_CMD_FALLING (FALLING interrupt, standard tape)

The device ACKs with CMD_EDGE_ACK before capture begins.

Model selection:
  -model c16       (default) C16 / Plus4 standard or Novaload
  -model c64                 C64 standard KERNAL tape (non-turbo)
  -model spectrum            ZX Spectrum standard ROM tape
  -model msx                 MSX standard tape (FSK Kansas City Standard, 1200 or 2400 baud)

ZX Spectrum notes:
  The Spectrum uses CHANGE (both edges) for its ROM loader — the edge mode
  command is sent automatically; no extra flags are needed.

  Output is a .tzx file by default (TZX v1.20, block 0x11 — Speed Loading /
  Direct Recording, compatible with Fuse, SpecEmu, ZXSpin, RealSpectrum, and
  any other TZX-capable emulator or hardware player such as TZXDuino).

  Pass --tap to produce a raw .tap file instead (compatible with Fuse --tape,
  ZX-Uno, etc.).  Both formats use the standard Spectrum ROM timing constants
  (3.5 MHz clock, CHANGE-edge sampling).

  Block type 0x13 (header) and 0x16 (data) are decoded if --prg is requested,
  saving each file as <name>.bin (load address embedded in the header).

  The Spectrum ROM loader uses CHANGE (both edges) — the CLI sends
  HOST_CMD_CHANGE automatically for -model spectrum.
"""

import argparse
import struct
import sys
import time
import re

try:
    import serial
except ImportError:
    print("ERROR: pyserial is required. Install with: pip install pyserial")
    sys.exit(1)

FIRMWARE_HZ = 2_000_000
BAUD        = 250_000

# ---------------------------------------------------------------------------
# Machine clock frequencies
# ---------------------------------------------------------------------------
C16_PAL_HZ  = 886_724
C16_NTSC_HZ = 894_886

C64_PAL_HZ  = 985_248
C64_NTSC_HZ = 1_022_727

# ZX Spectrum clock — always 3.5 MHz regardless of PAL/NTSC video
SPECTRUM_HZ = 3_500_000

# ---------------------------------------------------------------------------
# TAP magic bytes
# ---------------------------------------------------------------------------
TAP_MAGIC_C16 = b"C16-TAPE-RAW"
TAP_MAGIC_C64 = b"C64-TAPE-RAW"

TAP_VERSION  = 2    # C16 Novaload / half-wave (24-byte header)
TAP_RESERVED = 0

# ---------------------------------------------------------------------------
# Device → Host control commands
# ---------------------------------------------------------------------------
CMD_PLAY_PRESSED  = 0x01
CMD_PLAY_RELEASED = 0x02
CMD_OVERFLOW      = 0x03
CMD_EDGE_ACK      = 0x04   # Device confirms edge-mode change

# ---------------------------------------------------------------------------
# Host → Device command frame: 0xFF 0xFF 0xFF <cmd>
# ---------------------------------------------------------------------------
HOST_CMD_FALLING = 0x10   # Standard tape (FALLING edge)
HOST_CMD_CHANGE  = 0x11   # Novaload turbo / Spectrum (CHANGE — both edges)

MAX_RECORDING_TIMEOUTS = 15
EDGE_ACK_TIMEOUT_S     = 3.0

# ---------------------------------------------------------------------------
# C16 decoder constants
# ---------------------------------------------------------------------------
C16_SYNC1         = 0x16
C16_SYNC2         = 0x16
C16_BIT_THRESHOLD = 8000

# ---------------------------------------------------------------------------
# C64 decoder constants
# ---------------------------------------------------------------------------
# Pulse classification thresholds in C64 machine cycles.
# Short  < C64_SHORT_MAX  (< 512)
# Medium  C64_SHORT_MAX .. C64_MEDIUM_MAX-1 (512..767)
# Long   >= C64_MEDIUM_MAX (>= 768), includes leader pulses
C64_SHORT_MAX  = 512
C64_MEDIUM_MAX = 768

# Standard KERNAL sync: bytes 0x89 down to 0x81 (9 descending bytes)
C64_SYNC_START = 0x89
C64_SYNC_END   = 0x81

# TAP machine field for C64
C64_MACHINE_ID = 0   # 0 = C64, 1 = VIC-20, 2 = C16/Plus4

# ===========================================================================
# ZX Spectrum ROM timing constants (all in 3.5 MHz T-states)
# ---------------------------------------------------------------------------
#  Pilot tone:   2168 T-states per half-pulse
#  Sync pulse 1:  667 T-states
#  Sync pulse 2:  735 T-states
#  Bit 0:         855 T-states per half-pulse  (pair = 1710)
#  Bit 1:        1710 T-states per half-pulse  (pair = 3420)
#  Pilot length: >= 8000 half-pulses for a header block (type 0x00)
#               >= 3220 half-pulses for a data  block (type 0xFF)
#
# Classification thresholds (half-pulse lengths in T-states):
#   Pilot half-pulse  : 1800 ≤ p < 2600  (centred on 2168)
#   Sync-1 half-pulse :  550 ≤ p <  750  (centred on  667)
#   Sync-2 half-pulse :  650 ≤ p <  850  (centred on  735)
#   "0"-bit half-pulse:  700 ≤ p < 1050  (centred on  855)
#   "1"-bit half-pulse: 1450 ≤ p < 1950  (centred on 1710)
#
# In practice we use a single mid-point threshold to separate 0-bits from
# 1-bits after the sync sequence has been detected:
#   half-pulse < SPECTRUM_BIT_THRESHOLD → bit 0
#   half-pulse ≥ SPECTRUM_BIT_THRESHOLD → bit 1
# ===========================================================================

SPECTRUM_PILOT_MIN    = 1800
SPECTRUM_PILOT_MAX    = 2600
SPECTRUM_SYNC1_MIN    =  550
SPECTRUM_SYNC1_MAX    =  750
SPECTRUM_SYNC2_MIN    =  650
SPECTRUM_SYNC2_MAX    =  850
SPECTRUM_BIT_THRESHOLD = 1100  # half-pulses below this → bit 0, above → bit 1
SPECTRUM_PILOT_MIN_COUNT = 100  # minimum pilot half-pulses before we declare a block

# Spectrum block flag byte values
SPECTRUM_FLAG_HEADER = 0x00
SPECTRUM_FLAG_DATA   = 0xFF

# Spectrum header block types (byte after flag)
SPECTRUM_HDR_PROGRAM  = 0x00
SPECTRUM_HDR_NUMARRAY = 0x01
SPECTRUM_HDR_CHARARRAY= 0x02
SPECTRUM_HDR_CODE     = 0x03

# ===========================================================================
# MSX tape constants (Kansas City Standard / FSK)
# ---------------------------------------------------------------------------
#
# MSX uses a variant of the Kansas City Standard (KCS) FSK encoding.
# The signal is captured in CHANGE mode (both edges), so each firmware tick
# interval represents a half-cycle of the carrier tone.
#
# The MSX BIOS uses a Z80 software delay loop rather than a fixed-frequency
# oscillator, so the actual pulse widths differ from pure KCS frequencies.
# At 1200 baud (default, from openMSX / MSX Technical Handbook):
#   Bit 0 → one  long  half-cycle at ~512 Hz  →  half-period ≈  976 µs ≈ 1952 firmware ticks
#   Bit 1 → two short half-cycles at ~1024 Hz →  half-period ≈  488 µs ≈  976 firmware ticks
#
# At 2400 baud (high-speed mode used by some software):
#   Bit 0 → one  long  half-cycle at ~1024 Hz →  half-period ≈  488 µs ≈  976 firmware ticks
#   Bit 1 → two short half-cycles at ~2048 Hz →  half-period ≈  244 µs ≈  488 firmware ticks
#
# Framing: 1 start bit (0), 8 data bits LSB-first, 2 stop bits (1)
#
# A "long" header tone is at the bit-1 frequency for ~6.7 seconds before
# the 8-byte CAS sync marker: 1F A6 DE BA CC 13 7D 74
# A "short" header is ~1.7 seconds of the bit-1 frequency.
#
# File type markers (10 bytes each, following the CAS sync header):
#   D3 D3 D3 D3 D3 D3 D3 D3 D3 D3  BASIC tokenised
#   EA EA EA EA EA EA EA EA EA EA  ASCII / TEXT
#   D0 D0 D0 D0 D0 D0 D0 D0 D0 D0  Binary / machine code (BSAVE)
#
# Header record: 6-byte filename (space-padded), followed by file-type-specific
# fields (start address, end address, entry address for binary files).
# ===========================================================================

MSX_CAS_SYNC  = bytes([0x1F, 0xA6, 0xDE, 0xBA, 0xCC, 0x13, 0x7D, 0x74])

MSX_TYPE_BASIC  = 0xD3   # tokenised BASIC
MSX_TYPE_ASCII  = 0xEA   # ASCII / text
MSX_TYPE_BINARY = 0xD0   # BSAVE binary / machine code

MSX_TYPE_NAMES = {
    MSX_TYPE_BASIC:  "BASIC",
    MSX_TYPE_ASCII:  "ASCII",
    MSX_TYPE_BINARY: "Binary",
}

# Half-cycle duration thresholds in firmware 2 MHz ticks.
# We detect a bit by examining the mean half-cycle length within a burst:
#   bit 1 → short half-cycles (high frequency)
#   bit 0 → long half-cycles  (low frequency)
# Threshold is set at the geometric mean of the two expected values.
#
# 1200 baud: bit1 half ≈ 976 ticks, bit0 half ≈ 1952 ticks → threshold ≈ 1464
# 2400 baud: bit1 half ≈ 488 ticks, bit0 half ≈  976 ticks → threshold ≈  732
# Thresholds derived from observed real hardware captures.
# At 1200 baud the two half-period clusters sit at ~430 ticks (bit-1, short)
# and ~840 ticks (bit-0, long), with a clean gap between 600 and 700 ticks.
# Threshold 649 sits in the middle of that gap and is robust to ±15% speed variation.
#   1200 baud: bit-1 short cluster ≈ 350–600 ticks  (~225 µs half-period)
#              bit-0 long  cluster ≈ 700–1000 ticks (~425 µs half-period)
#   2400 baud: half the durations → threshold ≈ 322
MSX_BIT_THRESHOLD_1200 = 649   # ticks — below: bit 1,  above: bit 0
MSX_BIT_THRESHOLD_2400 = 322   # ticks — below: bit 1,  above: bit 0

# Minimum number of consecutive bit-1 half-pulses to qualify as a header tone
MSX_HEADER_MIN_PULSES = 200

# The 8-byte CAS sync word, transmitted MSB-first with KCS framing
# MSX_SYNC_BYTES: used only when WRITING .cas output files, not present on physical tape
MSX_SYNC_BYTES = [0x1F, 0xA6, 0xDE, 0xBA, 0xCC, 0x13, 0x7D, 0x74]

# TZX constants
TZX_SIGNATURE = b"ZXTape!"
TZX_EOF_MARKER = 0x1A
TZX_VERSION_MAJOR = 1
TZX_VERSION_MINOR = 20

# TZX block IDs used
TZX_BLOCK_STANDARD    = 0x10   # Standard Speed Data Block
TZX_BLOCK_TURBO       = 0x11   # Turbo Speed Data Block (used for raw direct-recording)
TZX_BLOCK_PURE_TONE   = 0x12   # Pure Tone
TZX_BLOCK_PULSE_SEQ   = 0x13   # Pulse Sequence
TZX_BLOCK_PURE_DATA   = 0x14   # Pure Data Block
TZX_BLOCK_DIRECT      = 0x15   # Direct Recording Block
TZX_BLOCK_TEXT_DESC   = 0x30   # Text Description (used for info comments)
TZX_BLOCK_ARCHIVE     = 0x32   # Archive Info


# ===========================================================================
# MSX tape decoder — FSK / Kansas City Standard
# ===========================================================================
#
# The MSX ROM loader uses CHANGE (both-edge) interrupt sampling, so the
# firmware delivers one tick value per signal edge (half-cycle boundary).
# We convert firmware 2 MHz ticks to microseconds and classify each
# half-cycle as belonging to a "short" (bit-1 carrier) or "long" (bit-0
# carrier) burst.
#
# Decoding strategy:
#   1. Scan for the header tone: a long run of consecutive "short"
#      half-pulses (bit-1 frequency).
#   2. After the header, detect the 8-byte CAS sync word.
#   3. Decode bytes (1 start bit + 8 data bits LSB-first + 2 stop bits)
#      until the signal ends.
#   4. Repeat from step 1 for the next block (short-header delimiter).
# ===========================================================================

def _msx_half_pulse_to_bit(ticks, threshold):
    return 1 if ticks < threshold else 0


def _msx_decode_byte(pulses, pos, threshold):
    """Decode one KCS byte (start + 8 data bits LSB-first + 2 stop) from pulses[pos].
    Returns (byte_value, next_pos) or (None, pos) on failure."""
    n = len(pulses)

    def read_bit(i):
        if i >= n:
            return None, i
        bit = _msx_half_pulse_to_bit(pulses[i], threshold)
        count = 4 if bit == 1 else 2
        j = i + count
        if j > n:
            j = n
        return bit, j

    start_bit, p = read_bit(pos)
    if start_bit is None or start_bit != 0:
        return None, pos
    bv = 0
    for bi in range(8):
        b, p = read_bit(p)
        if b is None:
            return None, pos
        bv |= b << bi
    # consume stop bits (don't fail if missing at end of tape)
    for _ in range(2):
        b, p = read_bit(p)
        if b is None:
            break
    return bv, p


def _msx_find_header(pulses, scan_from, threshold, min_pulses):
    """Find a run of >= min_pulses consecutive short (bit-1) half-pulses.
    Returns index of first pulse AFTER the run, or -1."""
    n = len(pulses)
    i = scan_from
    while i < n:
        if _msx_half_pulse_to_bit(pulses[i], threshold) == 1:
            j = i
            while j < n and _msx_half_pulse_to_bit(pulses[j], threshold) == 1:
                j += 1
            if j - i >= min_pulses:
                return j
            i = j + 1
        else:
            i += 1
    return -1


def extract_msx_blocks(pulses, baud=1200):
    """Decode MSX KCS tape blocks from the raw firmware pulse stream.

    MSX tape structure (per block):
      [header tone: long run of bit-1 pulses]
      [header record: 10x type-marker + 6-char filename + type-specific fields]
      [short header tone: shorter run of bit-1 pulses]
      [data body: raw payload bytes]

    Returns a list of dicts with keys: type_byte, type_name, filename, data, block_idx.
    Consecutive pairs of raw blocks are matched as (header_record, data_body).
    """
    threshold = MSX_BIT_THRESHOLD_1200 if baud == 1200 else MSX_BIT_THRESHOLD_2400

    # ── Phase 1: decode all raw blocks ──────────────────────────────────────
    raw_blocks = []
    scan_pos   = 0

    while scan_pos < len(pulses):
        after_header = _msx_find_header(pulses, scan_pos, threshold, MSX_HEADER_MIN_PULSES)
        if after_header < 0:
            break

        pos        = after_header
        data       = bytearray()
        n          = len(pulses)
        fail_streak = 0

        while pos < n:
            if _msx_half_pulse_to_bit(pulses[pos], threshold) == 1:
                j = pos
                while j < n and _msx_half_pulse_to_bit(pulses[j], threshold) == 1:
                    j += 1
                if j - pos >= 500:
                    break
                pos = j
                continue

            b, next_pos = _msx_decode_byte(pulses, pos, threshold)
            if b is None:
                fail_streak += 1
                if fail_streak > 20:
                    break
                pos += 1
                continue

            fail_streak = 0
            data.append(b)
            pos = next_pos

        if data:
            raw_blocks.append(bytes(data))
        scan_pos = pos if pos > after_header else after_header + 1

    # ── Phase 2: classify and pair blocks ───────────────────────────────────
    # Each file on tape is two raw blocks: a header record followed by a data body.
    # The header record starts with 10 identical type-marker bytes.
    # The data body follows immediately (next raw block).
    blocks    = []
    block_idx = 0
    i         = 0

    while i < len(raw_blocks):
        data = raw_blocks[i]

        # Detect type marker: look for 5+ identical bytes of a known type at start
        type_byte = None
        for candidate in (MSX_TYPE_BASIC, MSX_TYPE_ASCII, MSX_TYPE_BINARY):
            if len(data) >= 5 and all(x == candidate for x in data[:5]):
                type_byte = candidate
                break

        if type_byte is not None:
            # This is a header record — pair with the next raw block (data body)
            type_name = MSX_TYPE_NAMES.get(type_byte, f"Unknown({type_byte:#04x})")
            filename  = None
            if len(data) >= 16:
                filename = data[10:16].rstrip(b"\x00\x20").decode("ascii", errors="replace")

            # Append header record block
            blocks.append({
                "type_byte": type_byte,
                "type_name": type_name,
                "filename":  filename,
                "data":      data,
                "block_idx": block_idx,
                "role":      "header",
            })
            block_idx += 1
            i += 1

            # Append data body block if present
            if i < len(raw_blocks):
                body = raw_blocks[i]
                blocks.append({
                    "type_byte": type_byte,
                    "type_name": type_name,
                    "filename":  filename,
                    "data":      body,
                    "block_idx": block_idx,
                    "role":      "data",
                })
                block_idx += 1
                i += 1
        else:
            # Unrecognised block — include as-is
            type_byte = data[0] if data else 0xFF
            blocks.append({
                "type_byte": type_byte,
                "type_name": MSX_TYPE_NAMES.get(type_byte, f"Unknown({type_byte:#04x})"),
                "filename":  None,
                "data":      data,
                "block_idx": block_idx,
                "role":      "unknown",
            })
            block_idx += 1
            i += 1

    return blocks


def build_msx_cas(blocks):
    """
    Build an MSX .cas byte string from decoded blocks.

    Each block is preceded by the 8-byte CAS sync header.
    If blocks is empty, returns an empty bytes object.

    The raw data from each block (including the type-marker bytes and filename)
    is written verbatim so the .cas file is byte-for-byte compatible with
    openMSX, fMSX, CASDuino, and wav2cas.
    """
    cas = bytearray()
    for blk in blocks:
        cas += MSX_CAS_SYNC
        cas += blk["data"]
    return bytes(cas)


def print_msx_blocks(blocks):
    """Pretty-print decoded MSX tape blocks."""
    print()
    for blk in blocks:
        idx   = blk["block_idx"]
        tname = blk["type_name"]
        fname = blk["filename"] or "(unnamed)"
        dlen  = len(blk["data"])
        role  = blk.get("role", "")
        role_str = " [header]" if role == "header" else " [data]" if role == "data" else ""

        addr_str = ""
        if role == "header" and blk["type_byte"] == MSX_TYPE_BINARY:
            d = blk["data"]
            if len(d) >= 22:
                start = d[16] | (d[17] << 8)
                end   = d[18] | (d[19] << 8)
                entry = d[20] | (d[21] << 8)
                addr_str = f"  load=${start:04X} end=${end:04X} entry=${entry:04X}"

        print(f'  Block {idx}: {tname:<8}  "{fname}"{role_str}  ({dlen} bytes){addr_str}')
    print()


def write_msx_output(args, blocks, pulses, output_path):
    """
    Write the MSX .cas output file and optionally extract binary/BASIC files.
    """
    cas_bytes = build_msx_cas(blocks)

    if cas_bytes:
        with open(output_path, "wb") as f:
            f.write(cas_bytes)
        print(f"✅ CAS written: {output_path} ({len(cas_bytes):,} B)")
    else:
        print("⚠  No MSX blocks decoded — CAS file is empty.")
        print("   Check tape baud rate (try --baud 2400 for high-speed tapes)")
        return

    if args.prg and blocks:
        for blk in blocks:
            # Only extract from data body blocks, not header records
            if blk.get("role") == "header":
                continue
            d     = blk["data"]
            fname = (blk["filename"] or f"block{blk['block_idx']}").strip()
            safe  = "".join(c if c.isalnum() or c in "_-" else "_" for c in fname)[:8] or "NONAME"

            if blk["type_byte"] == MSX_TYPE_BINARY:
                bin_fn = f"{safe}.bin"
                with open(bin_fn, "wb") as f:
                    f.write(d)
                print(f"  ✅ BIN: {bin_fn} ({len(d)} B)")

            elif blk["type_byte"] == MSX_TYPE_BASIC:
                bas_fn = f"{safe}.bas"
                with open(bas_fn, "wb") as f:
                    f.write(d)
                print(f"  ✅ BAS: {bas_fn} ({len(d)} B)")

            elif blk["type_byte"] == MSX_TYPE_ASCII:
                asc_fn = f"{safe}.asc"
                with open(asc_fn, "wb") as f:
                    f.write(d)   # fixed: was 'payload' (undefined); now correctly 'd'
                print(f"  ✅ ASC: {asc_fn} ({len(d)} B)")

# ===========================================================================
# TAP header builders
# ===========================================================================

def tap_header_c16(data_len, ntsc=False, version=None):
    """
    Build a C16-TAPE-RAW TAP header.
    version=1  Full-wave (FALLING-edge, standard KERNAL). 20-byte header.
    version=2  Half-wave (CHANGE/both-edges, Novaload). 24-byte header + sample_rate.
    """
    if version is None:
        version = TAP_VERSION

    system_id   = 0   # Plus/4 (0 for bare C16/C116)
    video_id    = 1 if ntsc else 0
    sample_rate = C16_NTSC_HZ if ntsc else C16_PAL_HZ

    header = struct.pack(
        "<12sBBBBI",
        TAP_MAGIC_C16,
        version,
        system_id,
        video_id,
        TAP_RESERVED,
        data_len,
    )
    if version >= 2:
        header += struct.pack("<I", int(sample_rate))
    return header


def tap_header_c64(data_len, ntsc=False):
    """
    Build a C64-TAPE-RAW TAP header (version 1, 20 bytes).
    Version 1 supports 3-byte overflow pulses.
    Machine byte 0 = C64.  Video byte 0 = PAL, 1 = NTSC.
    """
    video_id = 1 if ntsc else 0
    return struct.pack(
        "<12sBBBBI",
        TAP_MAGIC_C64,
        1,             # TAP version 1 (overflow support)
        C64_MACHINE_ID,
        video_id,
        TAP_RESERVED,
        data_len,
    )

# ===========================================================================
# Common pulse encoder (used by C16 and C64 models)
# ===========================================================================
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

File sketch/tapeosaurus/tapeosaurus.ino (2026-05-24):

/*
 * Tapeosaurus — Wemos D1 Mini (ESP8266)
 * Commodore 16 / Plus/4 TAP capture
 * Works with tapeosaurus.py at 250000 baud.
 *
 * Pin mapping:
 *   D6 / GPIO12 → READ  from Datasette  (via 10k/20k divider → 3.3V)
 *   D5 / GPIO14 → SENSE from Datasette  (INPUT_PULLUP, switch to GND)
 *   D4 / GPIO2  → Onboard LED           (active LOW: ON while recording)
 *   D7 / GPIO13 → Passive piezo speaker (optional, safe output pin)
 *   D1 / GPIO5  → Overflow LED
 *
 * Edge mode is set at runtime via host command from tapeosaurus.py.
 * Default is FALLING (standard C16 tape).
 * Send 0xFF 0xFF 0xFF 0x11 (HOST_CMD_CHANGE)  → Novaload / turbo loaders.
 * Send 0xFF 0xFF 0xFF 0x10 (HOST_CMD_FALLING) → standard tape (default).
 * The device ACKs with 0x00 0x00 0x00 0x04 (CMD_EDGE_ACK).
 *
 * Data frame (device → host):  b0 b1 b2 (b0^b1^b2)
 * Control frame (device → host): 0x00 0x00 0x00 <cmd>
 * Command frame (host → device): 0xFF 0xFF 0xFF <cmd>
 */

#include <Arduino.h>
#include <ESP8266WiFi.h>

// Set to 1 to capture without waiting for PLAY — useful for isolating
// READ wiring issues when SENSE detection is suspected
#define CAPTURE_WITHOUT_SENSE  0

#define PIN_READ         12    // D6
#define PIN_SENSE        14    // D5
#define PIN_LED           2    // D4
#define PIN_PIEZO        13    // D7 — Safe output, not a bootstrap pin
#define PIN_LED_OVERFLOW  5    // D1

#define PIEZO_BIT  (1u << PIN_PIEZO)
#define PIEZO_TOGGLE() do { \
    if (GPO & PIEZO_BIT) GPOC = PIEZO_BIT; \
    else                 GPOS = PIEZO_BIT; \
} while (0)
#define PIEZO_OFF() (GPOC = PIEZO_BIT)

#define CLOCK_SCALE 40
#define BUF_SIZE 4096
#define BUF_MASK (BUF_SIZE - 1)

volatile uint32_t ring[BUF_SIZE];
volatile uint16_t r_head = 0;
volatile uint16_t r_tail = 0;

volatile uint32_t last_cycle = 0;
volatile bool capturing = false;
volatile bool overflow_flag = false;

#define DEBOUNCE_MS 60
static bool sense_prev = HIGH;
static unsigned long sense_ms = 0;

// ---------------------------------------------------------------------------
// Device → Host control commands
// ---------------------------------------------------------------------------
#define CMD_PLAY_PRESSED   0x01
#define CMD_PLAY_RELEASED  0x02
#define CMD_OVERFLOW       0x03
#define CMD_EDGE_ACK       0x04   // Sent after an edge-mode change is applied

// ---------------------------------------------------------------------------
// Host → Device command frame: 0xFF 0xFF 0xFF <cmd>
// ---------------------------------------------------------------------------
#define HOST_CMD_FALLING   0x10   // Switch ISR to FALLING (standard tape)
#define HOST_CMD_CHANGE    0x11   // Switch ISR to CHANGE  (Novaload / turbo)

// ---------------------------------------------------------------------------
// Runtime edge mode — default FALLING, changed by host command
// ---------------------------------------------------------------------------
static uint8_t current_edge_mode = FALLING;

// ---------------------------------------------------------------------------
// ISR
// ---------------------------------------------------------------------------
void IRAM_ATTR onReadISR() {
    uint32_t now = ESP.getCycleCount();

#if CAPTURE_WITHOUT_SENSE
    bool active = true;
#else
    bool active = capturing;
#endif

    if (active) PIEZO_TOGGLE();

    if (!active) {
        last_cycle = now;
        return;
    }

    if (last_cycle != 0) {
        uint32_t ticks = (now - last_cycle) / CLOCK_SCALE;
        if (ticks == 0) ticks = 1;
        if (ticks > 0x00FFFFFFul) ticks = 0x00FFFFFFul;

        uint16_t next = (r_head + 1) & BUF_MASK;
        if (next == r_tail) {
            overflow_flag = true;
        } else {
            ring[r_head] = ticks;
            r_head = next;
        }
    }

    last_cycle = now;
}

// ---------------------------------------------------------------------------
// Helpers
// ---------------------------------------------------------------------------
static void send_control(uint8_t cmd) {
    uint8_t ctrl[4] = {0x00, 0x00, 0x00, cmd};
    Serial.write(ctrl, 4);
}

static void set_edge_mode(uint8_t mode) {
    // Re-attaching the interrupt while capturing is valid but unusual;
    // typically Python sends this command before pressing PLAY.
    detachInterrupt(digitalPinToInterrupt(PIN_READ));
    current_edge_mode = mode;
    attachInterrupt(digitalPinToInterrupt(PIN_READ), onReadISR, mode);
}

// ---------------------------------------------------------------------------
// Parse one 4-byte host-command frame from Serial (non-blocking)
// ---------------------------------------------------------------------------
static void handle_host_commands() {
    // Each host frame is exactly 4 bytes: 0xFF 0xFF 0xFF <cmd>
    // We only enter when enough bytes are waiting to avoid any blocking read.
    while (Serial.available() >= 4) {
        uint8_t buf[4];
        Serial.readBytes(buf, 4);

        if (buf[0] == 0xFF && buf[1] == 0xFF && buf[2] == 0xFF) {
            switch (buf[3]) {
                case HOST_CMD_FALLING:
                    set_edge_mode(FALLING);
                    send_control(CMD_EDGE_ACK);
                    break;
                case HOST_CMD_CHANGE:
                    set_edge_mode(CHANGE);
                    send_control(CMD_EDGE_ACK);
                    break;
                default:
                    // Unknown command — ignore silently
                    break;
            }
        }
        // Non-matching frames (e.g. noise) are discarded; we've already
        // consumed the 4 bytes so the stream stays aligned.
    }
}

// ---------------------------------------------------------------------------
// Setup / loop
// ---------------------------------------------------------------------------
void setup() {
    WiFi.persistent(false);
    WiFi.mode(WIFI_OFF);
    WiFi.forceSleepBegin();
    delay(1);

    Serial.begin(250000);

    pinMode(PIN_PIEZO, OUTPUT);
    PIEZO_OFF();

    pinMode(PIN_LED_OVERFLOW, OUTPUT);
    digitalWrite(PIN_LED_OVERFLOW, HIGH);

    pinMode(PIN_LED, OUTPUT);
    digitalWrite(PIN_LED, HIGH);

    pinMode(PIN_READ, INPUT);
    pinMode(PIN_SENSE, INPUT_PULLUP);

    sense_prev = digitalRead(PIN_SENSE);

    // Attach with the default edge mode (FALLING).
    // Python will send HOST_CMD_CHANGE before capture starts if needed.
    attachInterrupt(digitalPinToInterrupt(PIN_READ), onReadISR, current_edge_mode);
}
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

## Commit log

2026-05-25 CAD model fixes
    [Tapeosaurus - Main body.stl, Tapeosaurus.f3d]
2026-05-26 CAD files fixes
    [A (1).stl, A.stl, CBM Logo 1.stl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]
2026-05-27 enclosure images added
    [Tapeosaurus.f3d]
